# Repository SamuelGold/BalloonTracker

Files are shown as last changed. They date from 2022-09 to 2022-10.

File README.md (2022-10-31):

# Weather Balloon Tracker project

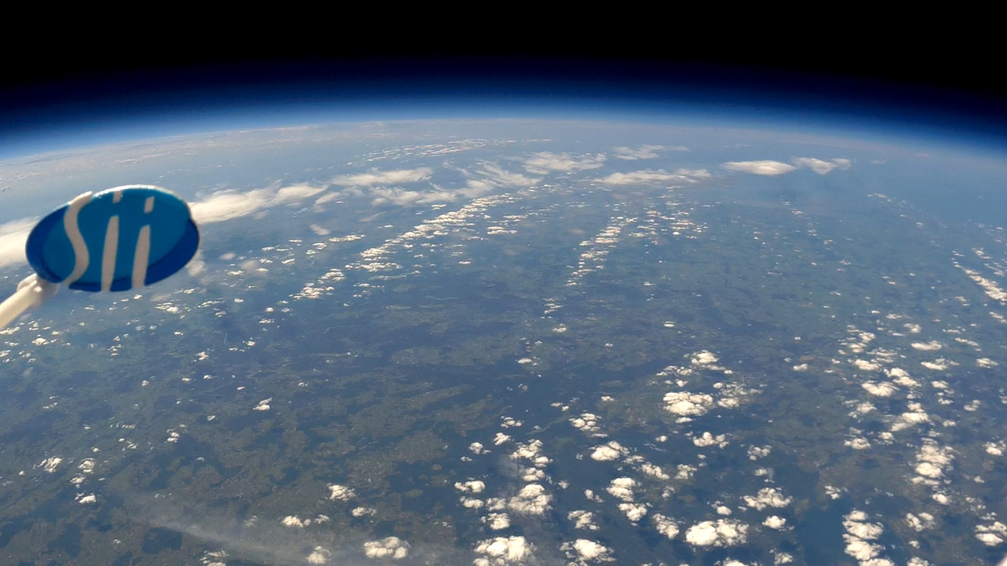
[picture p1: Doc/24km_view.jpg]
Camera view


An amateur project of sending a weather balloon up to the sky. The balloon was successfully launched at more than 24km height and it was found after landing. The project was sponsored by Sii Poland company where I'm working at.

Project consists the balloon, landing parachute, air station inside the payload and Groung station:

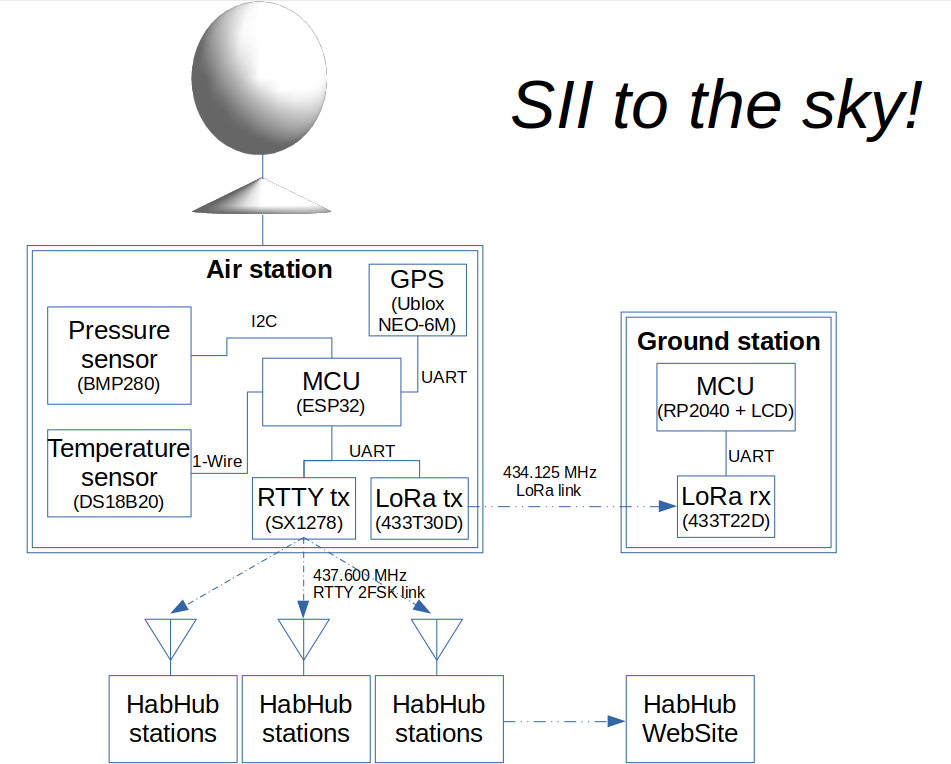
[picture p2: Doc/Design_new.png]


The prepared payload as it was just before the launch:

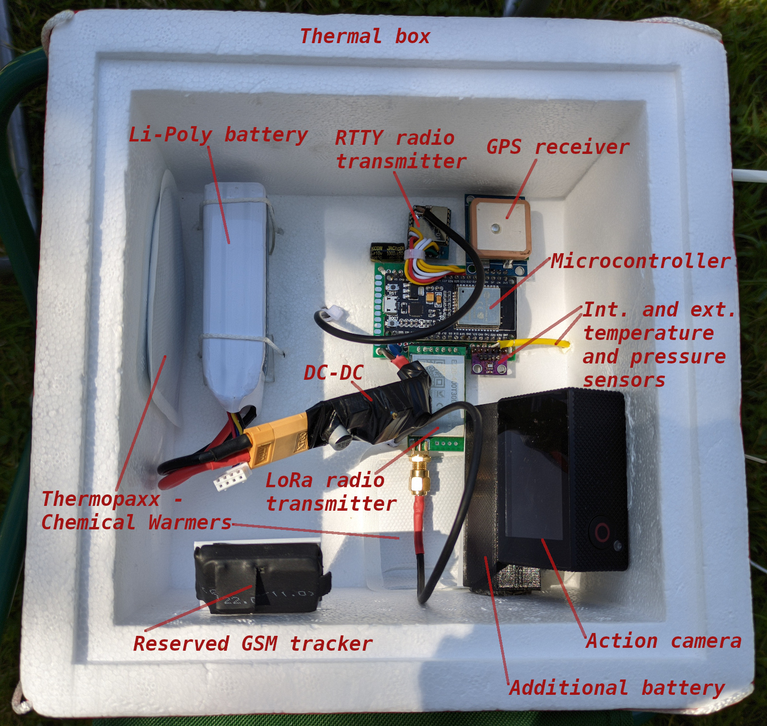
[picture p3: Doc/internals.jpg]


1800mAh 3S Li-Poly battery was used to power the air station. An additional 1850 Samsung battery was used to power an action camera to ensure its long working time. Because of the low temperature at the high altitudes, Thermopaxx chemical warmers were used to heat the batteries. A foam container with a wall thickness of 2.5 cm was used as an enclosure.
The total weight of the payload was about 650g.

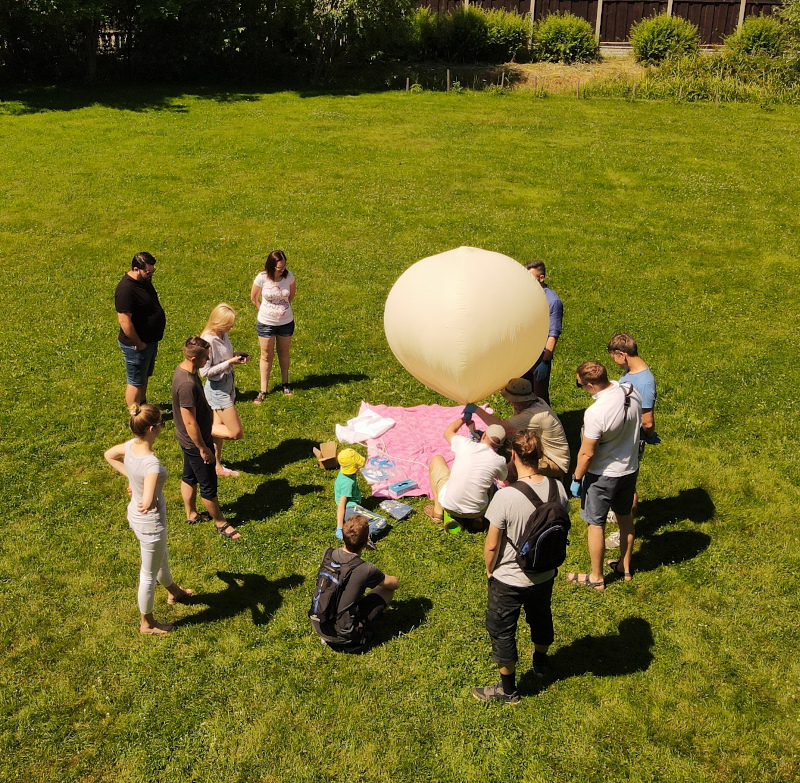
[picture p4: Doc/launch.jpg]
Preparing

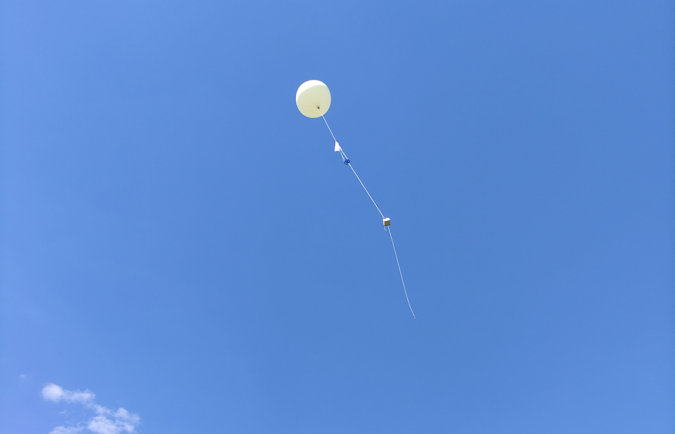
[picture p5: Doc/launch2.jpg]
Just launched


Signals from the air station were resieved in two ways: by the ground station and HabHub network. The ground station was saving each received packet into internal memory([Fly log](Doc/Fly_Chart.xlsx)). More technical details about the ground and air stations may be found in their subfolders(air station folder has the same name as the project).
Thanks to the logging we can see how the temperature was changing outside and inside the payload during the flight:
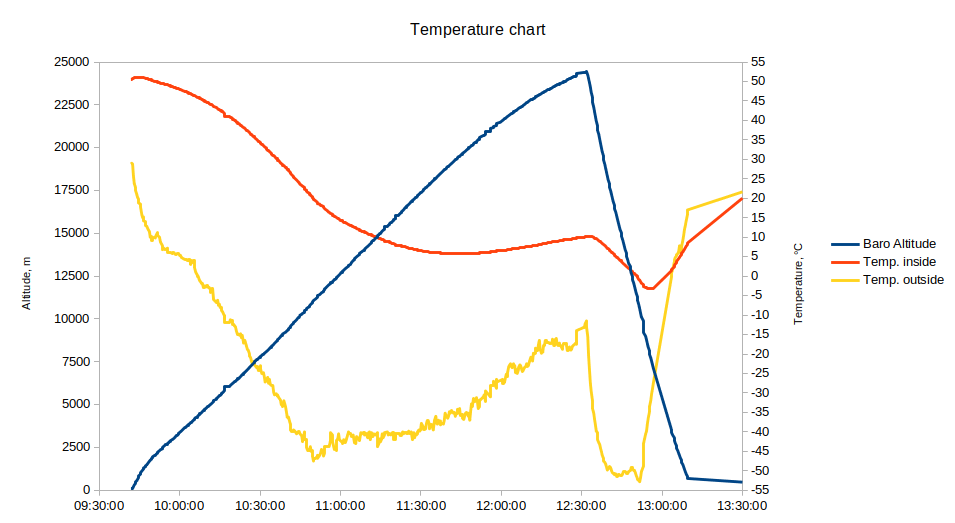
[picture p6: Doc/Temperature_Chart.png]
Temperature chart

Also we can see the pressure change:
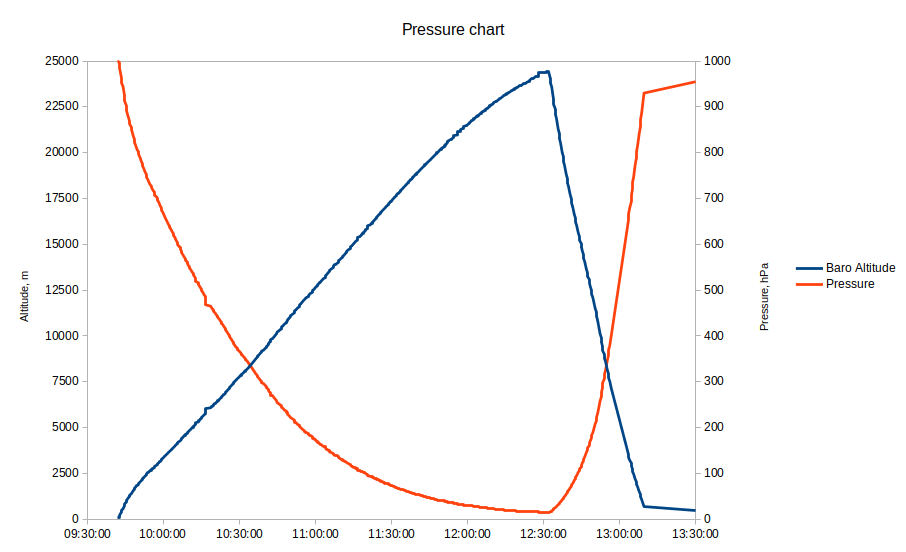
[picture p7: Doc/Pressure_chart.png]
Pressure chart


The payload was found at a distance of 104 km from the starting point:
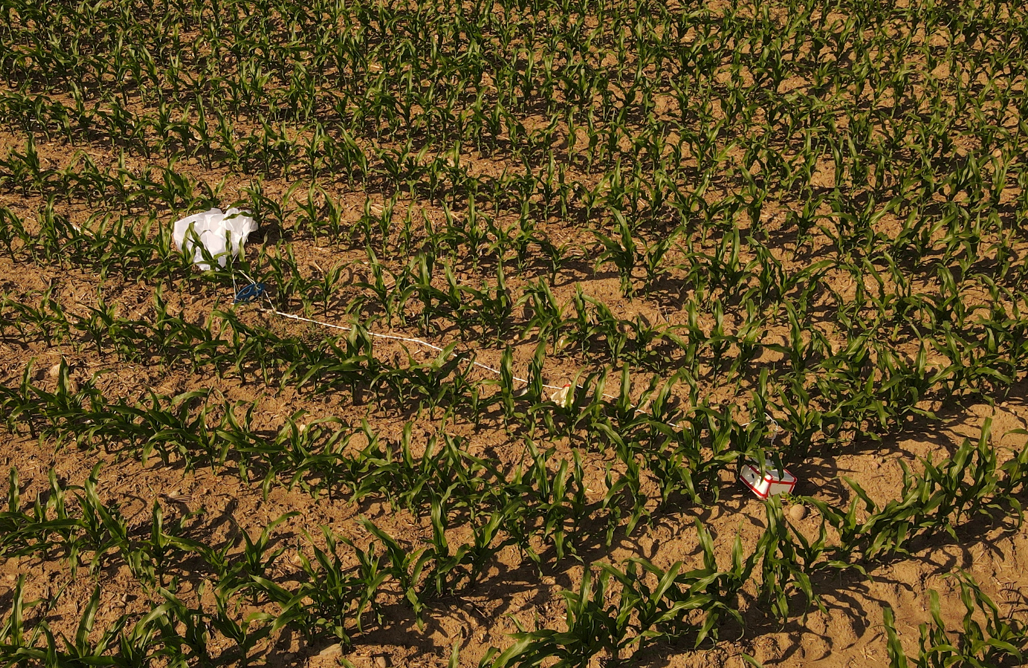
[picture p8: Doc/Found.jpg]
Found


Media from the internal camera and some external drone shots were compiled into a short film, enjoy :)
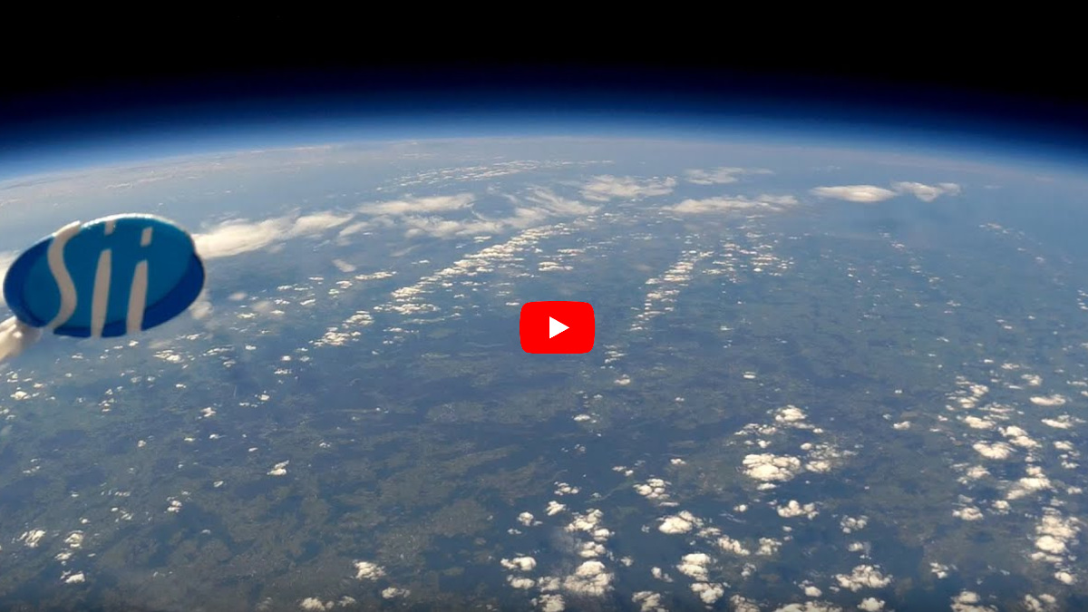
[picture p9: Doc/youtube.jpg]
A film about the weather balloon (https://www.youtube.com/watch?v=4AIsvloCAdA)


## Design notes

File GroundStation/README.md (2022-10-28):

# Ground station
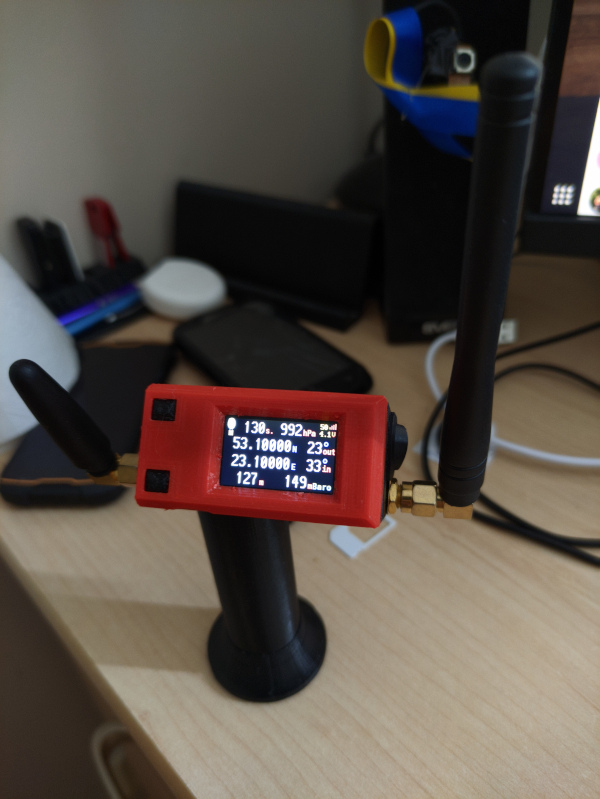
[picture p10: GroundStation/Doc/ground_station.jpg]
Ground station


The ground station is based on TTGO T-Display RP2040 board, programmed with embedded Python and powered by a single 18650 Li-pol battery. Ground station's LoRa receiver module (433T30D) is based on SX1278 chip and communicates with the controller by UART.
Initially it was planned to add a GSM module to the ground station, but GSM created some interferences with RP2040 that caused its reset. The front panel of the station was taken from https://www.thingiverse.com/thing:4501444 and the main body with the battery bay was created in FreeCAD (sources and models are in Case folder).
All received packets saved to FlyLog.txt file for the future processing.

Ground station catches the payload's signal near the landing place:
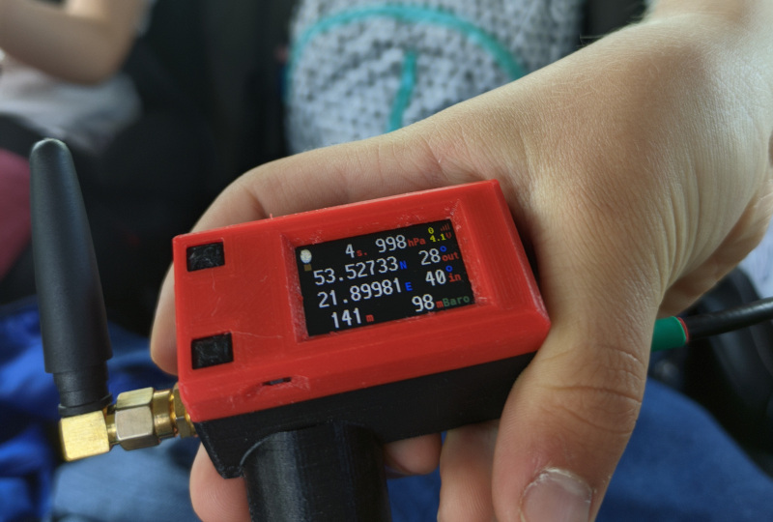
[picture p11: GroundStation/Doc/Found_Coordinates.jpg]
Coordinates


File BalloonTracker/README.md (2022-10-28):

# Air station

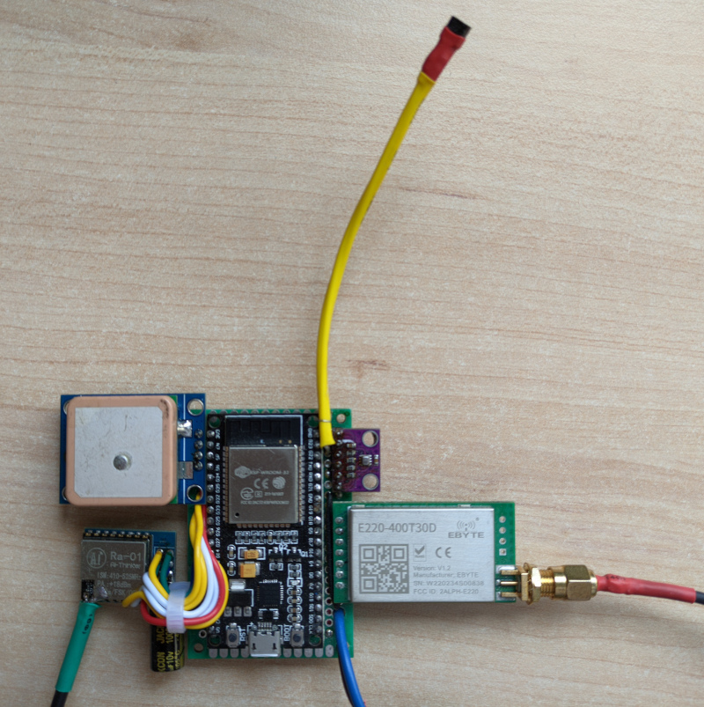
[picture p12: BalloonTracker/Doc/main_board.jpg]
Air station


The air station includes an internal temperature and pressure sensor(BMP280) and an external temperatute sensor(DS18B20) connected by I2C and 1-Wire interfaces to the main controller(ESP32). Position of the balloon received from GPS module(NEO-6M) via UART interface. It is not recommended to use NEO-6M module without reconfiguration, because with the default settings it looses position at high altitude, ATGM336H is highly recommended instead.
Telemetry delivered in two ways: 
* By RTTY transmission to HabHub high altitude balloons tracking system at 437.600MHz. During the launch about 5 HabHub stations were receiving the signal and sending the data to tracker.habhub.org website. Ra-01 SX1278 module is used for this purpose.
* By LoRa transmission to the ground station at 434.125MHz. The ground station displays the current position, temperature, altitude and saves historical data to internal memory. 433T30D (SX1278 + mcu and amplifier) module is used for LoRa transmission.

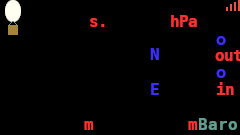
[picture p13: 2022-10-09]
GroundStation/bg.jpg

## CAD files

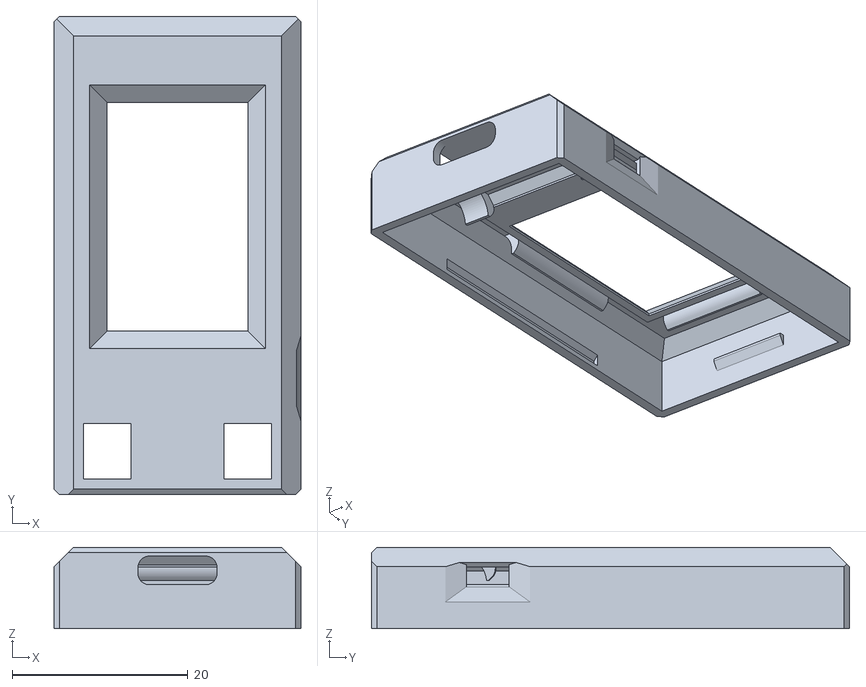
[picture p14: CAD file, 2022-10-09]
GroundStation/Case/TTGO_T-Display_Box_-_Top.stl
28.0 x 54.3 x 9.25

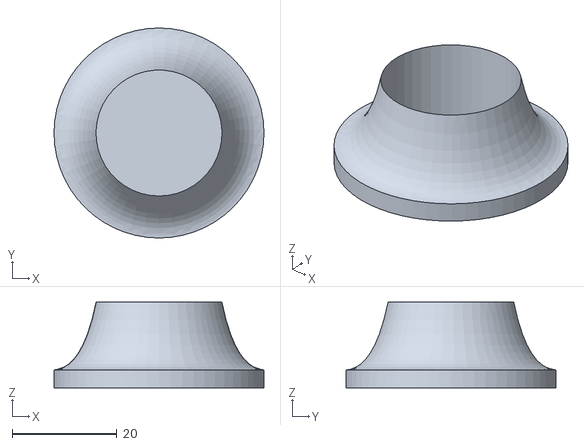
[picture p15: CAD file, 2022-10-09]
GroundStation/Case/ground_station_bottom_cap.stl
40.0 x 40.0 x 16.3

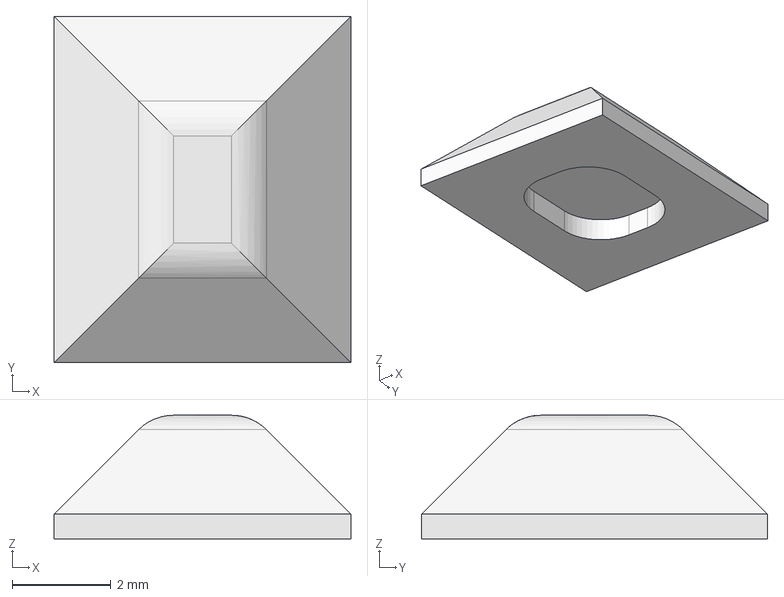
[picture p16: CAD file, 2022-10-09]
GroundStation/Case/ground_station_body.FCStd
6.00 x 7.00 x 2.50 mm

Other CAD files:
GroundStation/Case/ground_station_body.stl

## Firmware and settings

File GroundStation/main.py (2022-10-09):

"""
Weather baloon ground station
"""

from machine import UART,Pin
import random
import utime
import st7789
import tft_config
import vga1_8x16 as font
import vga1_16x32 as font_big
import binascii
from SIM800L import Modem
import json
import hashlib

tft = tft_config.config(3)

e220_m0 = Pin(14, Pin.OUT)
e220_m1 = Pin(15, Pin.OUT)
e220_aux = Pin(16, Pin.IN, Pin.PULL_UP)
e220_tx = Pin(13)
e220_rx = Pin(12)
e220_uart = UART(0, 9600, tx = e220_rx, rx = e220_tx)

e220_uart.init(9600, bits = 8, parity = None, stop = 1, timeout = 100)

gsm = Modem(MODEM_TX_PIN = 9, MODEM_RX_PIN = 8)

def e220_init():
    e220_m0.value(1)
    e220_m1.value(1)
    utime.sleep_ms(1)
    
    while ( not e220_aux.value() ):
        utime.sleep_ms(1)
        
    print("E220 AUX waiting done! Writing configuration...")   
#############################################################
    #set RX channel, 0x18 = 24 dec = 434.125MHz
    e220_uart.write(binascii.unhexlify("c0040118"))
    utime.sleep_ms(1)
    while ( (not e220_aux.value()) or e220_uart.read() ):
        print("Wait after frequency change...")
        utime.sleep_ms(100)

    if e220_uart.any():
        print("c0040117 setting result:", binascii.hexlify(e220_uart.readline()))
#############################################################
    #set broadcast RX
    e220_uart.write(binascii.unhexlify("c000020000"))
    #e220_uart.write(binascii.unhexlify("c00003111162"))
    utime.sleep_ms(1)
    while ( (not e220_aux.value()) or e220_uart.read() ):
        print("Wait after address change...")
        utime.sleep_ms(100)

    utime.sleep_ms(10)
    
    if e220_uart.any():
        print("c000020000 setting result:", binascii.hexlify(e220_uart.readline()))
#############################################################    
    e220_uart.write(binascii.unhexlify("c10008"))
    utime.sleep_ms(250)
    if e220_uart.any():
        print("Configuration:", binascii.hexlify(e220_uart.readline()))
#############################################################
    e220_m0.value(0)
    e220_m1.value(0)
    utime.sleep_ms(10)

    while ( (not e220_aux.value()) or e220_uart.read() ):
        print("Wait for the mode change")
        utime.sleep_ms(100)
    
    print("E220 initialzation finished ")

def display_gsm_signal(percent = 50):
    text = str(percent)
    tft.text(font, '█' * 3, 207, 0, st7789.BLACK, st7789.BLACK)
    tft.text(font, text, 207, 0, st7789.YELLOW, st7789.BLACK)

def display_gsm_bat(voltage = 4.0):
    voltage = round(voltage, 1)
    text = str(voltage)
    tft.text(font, '█' * 4, 206, 14, st7789.BLACK, st7789.BLACK)
    tft.text(font, text, 206, 14, st7789.YELLOW, st7789.BLACK)
    tft.text(font, 'V', 232, 14, st7789.RED, st7789.BLACK)
    
def print_line(line, x, y):
    length = len(line)
    tft.text(font_big, line, x - (length * 16), y - 26, st7789.WHITE, st7789.BLACK)
    
def clear_line(length, x, y):
    #tft.text(font_big, "X" * length, x - (length * 16), y - 26, st7789.RED, st7789.BLACK)
    tft.text(font_big, " " * length, x - (length * 16), y - 26, st7789.BLACK, st7789.BLACK)

#lat_lon
def display_lat_lon(lat_n, lon_e):
    clear_line(8, 147, 60)
    print_line(str(lat_n), 147, 60)
    clear_line(8, 147, 95)
    print_line(str(lon_e), 147, 95)
    
# hight
def display_height(m, m_baro):
    clear_line(5, 80, 129)
    print_line(str(m), 80, 129)
    clear_line(5, 185, 129)
    print_line(str(m_baro), 185, 129)

# hPa
def display_hpa(hpa):
    clear_line(4, 168, 27)
    print_line(str(hpa), 168, 27)

# seconds
def display_seconds(seconds):
    clear_line(4, 88, 27)
    print_line(str(seconds), 88, 27)

# *C
def display_temperature(c, c2):
    clear_line(3, 213, 60)
    print_line(str(c), 213, 60)
    clear_line(3, 213, 95)
    print_line(str(c2), 213, 95)

def verify_message(message):
    #b'$$NOCALL,3630,17:46:50,53.13479,23.17336,151,78,31.1,21.8,1000*74EB\n'
    info_array = []
    
    try:
        message_decoded = message.decode('ascii')
        print('Got message: ', message_decoded)
            
        splited_message = str(message_decoded).split(',')
                
        element = splited_message[1] # Packet number
        if (not element.isdigit()):
            print('packet number error:', element)
            return None
        info_array.append(element)

        element = splited_message[2] # Time
        if (len(element) != 8):
            print('Time decoding error:', element)
            return None
        info_array.append(element)

        element = splited_message[3] # Lat
        try:
            float(element)
        except ValueError:
            print('Lat decoding error:', element)
            return None
        info_array.append(element)

        element = splited_message[4] # Lon
        try:
            float(element)
        except ValueError:
            print('Lon decoding error:', element)
            return None
        info_array.append(element)

        element = splited_message[5] # Alt GPS
        if (not element.isdigit()):
            print('Alt GPS decoding error:', element)
            return None
        info_array.append(element)
        
        element = splited_message[6] # Alt Baro
        if (not element.isdigit()):
            print('Alt baro decoding error:', element)
            return None
        info_array.append(element)

        element = splited_message[7] # Temp int
        try:
            float(element)
        except ValueError:
            print('Temp int decoding error:', element)
            return None
        info_array.append(element)

        element = splited_message[8] # Temp out
        try:
            float(element)
        except ValueError:
            print('Temp Out decoding error:', element)
            return None
        info_array.append(element)

        element = splited_message[9].split('*')[0] # Baro
        if (not element.isdigit()):
            print('Baro decoding error:', element)
            return None
        info_array.append(element)

        return info_array
            
    except:
        return None
    
    return None

def log_file(message):
    f = open("fly_journal.txt")
    f.write("213\n")
    f.close()

def SaveLogFile(filename, dictionary):
    with open(filename, "a") as f:
        for key in range(0, len(dictionary)):
            if key != len(dictionary) - 1:
                f.write(str(dictionary[key]) + " ")
            else:
                f.write(str(dictionary[key]) + "\n")

tft.init()
tft.jpg(f'bg.jpg', 0, 0, st7789.SLOW)
gsm.initialize()
e220_init()

#gsm.connect(apn='internet', user='internet', pwd='internet')
#print('\nModem IP address: "{}"'.format(gsm.get_ip_addr()))
#print('\nNow running demo http GET...')
#url = 'http://checkip.dyn.com/'
#response = gsm.http_request(url, 'GET')
#print('Response status code:', response.status_code)
#print('Response content:', response.content)
display_gsm_signal(0)

#utime.sleep(1000)

e220_m0.value(0)
e220_m1.value(0)
utime.sleep_ms(100)

#s = '$$NOCALL,6374,16:18:44,53.13480,23.17329,130,91,28.2,19.2,999*EBDD\n'.split(',')

#status = {'Lat': str(s[3]),
#          'Lon': str(s[4]),
#          'Altitude_GPS': str(s[5]),
#          'ALtitude_Baro': str(s[6]),
#          'Temperature_in': int(float(str(s[7]))),
#          'Temperature_out': int(float(str(s[8]))),
#          'Pressure': str(s[9]).split('*')[0]}


#            _sentence_b64 = binascii.b2a_base64(message, newline=False).decode('ascii')
#            print("base64:", _sentence_b64)

#            _data = {
#                "type": "payload_telemetry",
#                "data": {
#                    "_raw": _sentence_b64
#                },
#                "receivers": {
#                    "N0CALL": {"time_created": "2022-06-19T17:12:13.174562Z", "time_uploaded": "2022-06-19T17:12:13.174562Z",},
#                },
#            }

#            json_data_str = str(_data)

#            print("Data:", json_data_str)

#            doc_id_hash = hashlib.sha256()
#            doc_id_hash.update(_sentence_b64)
#            doc_id_str = binascii.hexlify(doc_id_hash.digest()).decode('ascii')
#            print("DOC_ID:", doc_id_str)







#print(status)

#print("GSM signal info:", int(gsm.get_signal_strength() * 100))

n = 1
seconds = 0

while n != 0:
    #LoRa got: b'$$NOCALL,6618,11:31:42,0.00000,0.00000,0,136,29.0,27.8,994*3229\n'
    if e220_uart.any():
        message = verify_message(e220_uart.readline())
        if (message != None):
            display_hpa(message[8])
            display_height(message[4], message[5])
            display_lat_lon(message[2], message[3])
            display_temperature(int(float(str(message[7]))), int(float(str(message[6]))))
            SaveLogFile("/FlyLog.txt", message)
            seconds = 0

    display_seconds(seconds)
    bat_status = gsm.battery_status().split(',')    
    display_gsm_bat(float(bat_status[2])/1000)

    utime.sleep_ms(1000)
    seconds = seconds + 1

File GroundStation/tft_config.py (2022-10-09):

"""TTGO T-Display RP2040 display"""

from machine import Pin, SPI
from time import sleep
import st7789

TFA = 40 # top free area when scrolling
BFA = 40 # bottom free area when scrolling

def config(rotation=0, buffer_size=0, options=0):

    Pin(22, Pin.OUT, value=1)

    spi = SPI(0,
        baudrate=62500000,
        polarity=1,
        phase=0,
        sck=Pin(2, Pin.OUT),
        mosi=Pin(3, Pin.OUT),
        miso=None)

    return st7789.ST7789(
        spi,
        135,
        240,
        cs=Pin(5, Pin.OUT),
        dc=Pin(1, Pin.OUT),
        backlight=Pin(4, Pin.OUT),
        rotation=rotation,
        options=options,
        buffer_size=buffer_size)

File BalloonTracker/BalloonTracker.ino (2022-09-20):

/* Uncomment //#define RADIOLIB_STATIC_ONLY in BuildOpt.h to avoid RadioLib crash */

#include "Arduino.h"
#include "BalloonTracker.h"
#include <TinyGPSPlus.h>
#include <Adafruit_BMP280.h>
#include <OneWire.h>
#include <DallasTemperature.h>
#include <EEPROM.h>

// GPS NMEA parser
TinyGPSPlus gps;

// BMP280 sensor  SDA SCL 21, 22
Adafruit_BMP280 barometer; // I2C

// setup a oneWire instance to communicate with any OneWire devices
OneWire oneWire(23); // oneWire pin 23

// pass our oneWire reference to Dallas Temperature. 
DallasTemperature sensors(&oneWire);

// arrays to hold device address
DeviceAddress insideThermometer;

static bool barometer_found = false;
static bool ext_termo_found = false;
static int message_id = 0;

bool barometer_setup()
{
  unsigned status;

  status = barometer.begin(0x76);
  if (!status) {
    Serial.println(F("Could not find a valid BMP280 sensor, check wiring or "
                      "try a different address!"));
    return false;
  }

  barometer.setSampling(Adafruit_BMP280::MODE_NORMAL,     /* Operating Mode. */
                        Adafruit_BMP280::SAMPLING_X16,     /* Temp. oversampling */
                        Adafruit_BMP280::SAMPLING_X16,    /* Pressure oversampling */
                        Adafruit_BMP280::FILTER_X16,      /* Filtering. */
                        Adafruit_BMP280::STANDBY_MS_125); /* Standby time. */

  return true;
}

bool ds18b20_setup()
{
  sensors.begin();
  delay(100);
  
  Serial.print("Found ");
  Serial.print(sensors.getDeviceCount(), DEC);
  Serial.println(" devices.");

  Serial.print("Parasite power is: "); 
  if (sensors.isParasitePowerMode()) Serial.println("ON");
  else Serial.println("OFF");
  
  if (!sensors.getAddress(insideThermometer, 0))
  {
    Serial.println("Unable to find address for temperature Device 0");
  }

  sensors.setResolution(insideThermometer, 10);

  return true;
}

void setup() {
  Serial.begin(9600);
  Serial2.begin(9600);
  EEPROM.begin(512);
  
  while(!Serial || !Serial2){};
  delay(500);
  
  ext_termo_found = ds18b20_setup();
  barometer_found = barometer_setup();

  SetupRTTY();
  lora_setup();

  //EEPROM.put(0, message_id); // uncomment at the first flashing
  EEPROM.get(0, message_id);
}

void loop() {
  // sensors processing
  if (ext_termo_found)
  {
    float tempC = sensors.getTempC(insideThermometer);
  
    // Check if reading was successful
    if(tempC != DEVICE_DISCONNECTED_C) 
    {
      ball_info.temperature_outside = tempC;
    }
    else
    {
      ball_info.temperature_outside = 0;
    }
  }
  
  if (barometer_found)    // Check if the measurement is complete
  {
    ball_info.temperature_inside = barometer.readTemperature();
    ball_info.pressure = barometer.readPressure()/100;
    ball_info.altitude = barometer.readAltitude(1010.30);
  }
  
  // GPS processing
  while (Serial2.available())
  {
    char c = Serial2.read();
    gps.encode(c);
  }

  if (gps.location.isValid())
  {
    ball_info.latitude = gps.location.lat();
    ball_info.longitude = gps.location.lng();
  }

  if (gps.time.isValid())
  {
    ball_info.gps_time = gps.time.hour() * 10000 + gps.time.minute() * 100 + gps.time.second();

    snprintf(ball_info.gps_time_str, sizeof(ball_info.gps_time_str), "%02d:%02d:%02d",
             gps.time.hour(), gps.time.minute(), gps.time.second());
  }
  else
  {
    snprintf(ball_info.gps_time_str, sizeof(ball_info.gps_time_str), "00:00:00");
  }
           
  if (gps.date.isValid())
  {
    ball_info.gps_date = gps.date.day() * 10000 + gps.date.month() * 100 + gps.date.year();
  } 

  if (gps.altitude.isValid())
  {
    ball_info.gps_altitude = gps.altitude.meters();
  }


  char message[128] = {0};

  snprintf(message, sizeof(message), "%s%s,%i,%s,%.5f,%.5f,%i,%i,%.1f,%.1f,%i",
           RTTY_PREFIX, CALLSIGN, message_id, ball_info.gps_time_str, 
           ball_info.latitude, ball_info.longitude, ball_info.gps_altitude, ball_info.altitude,
           ball_info.temperature_inside, ball_info.temperature_outside, ball_info.pressure);

  unsigned int Count = strlen(message);
  
  // Calc CRC
  unsigned int CRC = 0xffff;           // Seed
  unsigned int xPolynomial = 0x1021;
  
  for (int i = strlen(RTTY_PREFIX); i < Count; i++)
  {   // For speed, repeat calculation instead of looping for each bit
    CRC ^= (((unsigned int)message[i]) << 8);
    for (int j=0; j<8; j++)
    {
        if (CRC & 0x8000)
            CRC = (CRC << 1) ^ 0x1021;
        else
            CRC <<= 1;
    }
  }
  
  message[Count++] = '*';
  message[Count++] = Hex((CRC >> 12) & 15);
  message[Count++] = Hex((CRC >> 8) & 15);
  message[Count++] = Hex((CRC >> 4) & 15);
  message[Count++] = Hex(CRC & 15);
  message[Count++] = '\n';  
  message[Count++] = '\0';
    
  Serial.print("Message: ");
  Serial.println(message);


  EEPROM.put(0, message_id++);
  EEPROM.commit();

  lora_message_send(message);

  delay(1000);

  rtty_message_send(message);

  if (ext_termo_found)
  {
    sensors.requestTemperatures();
  }
  
  delay(10000);
}

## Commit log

2022-09-20 Working version plus ground station
2022-10-09 Documentation, 3d models, images and python modules added.
    [Fly_Chart.xlsx, TTGO_T-Display_Box_-_Top.stl, ground_station_body.FCStd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]
2022-10-09 Project files moved to BalloonTracker folder, clearance
    [BalloonTracker.h, BalloonTracker.ino, Radio.ino]
2022-10-31 Launched balloon image inserted.
